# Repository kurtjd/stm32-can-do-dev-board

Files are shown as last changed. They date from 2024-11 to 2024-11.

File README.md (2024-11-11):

# STM32 CAN-Do! Development Board
|Layout|3D View|
|---|---|
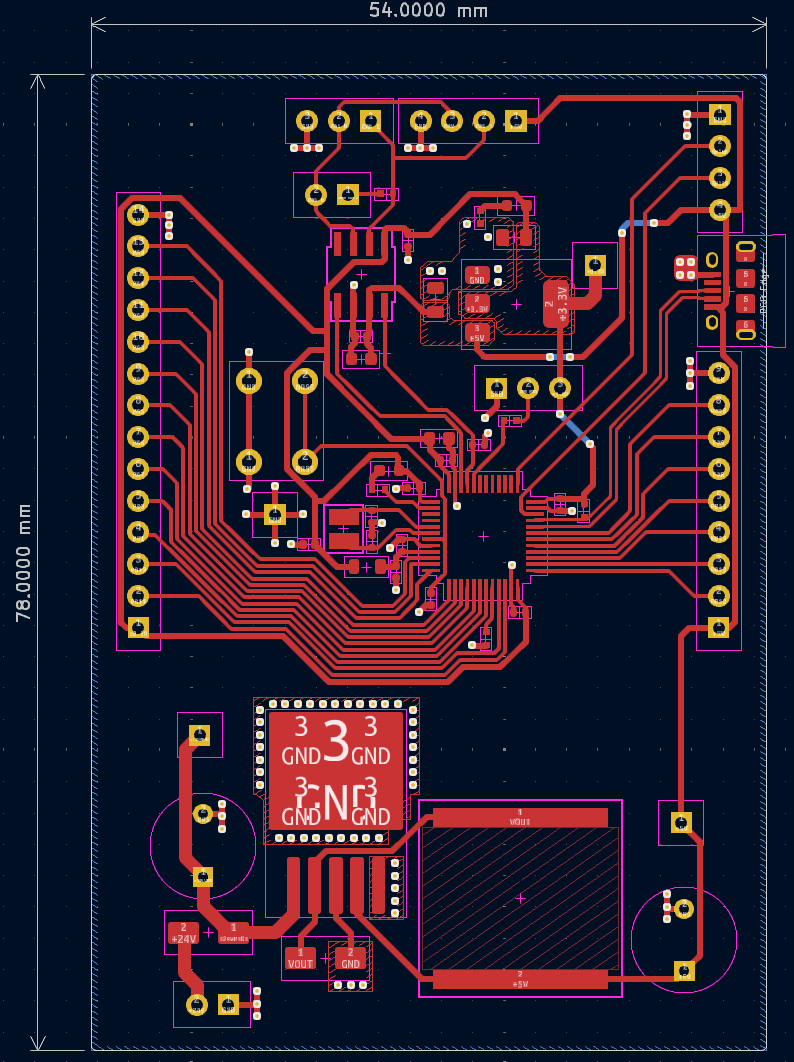
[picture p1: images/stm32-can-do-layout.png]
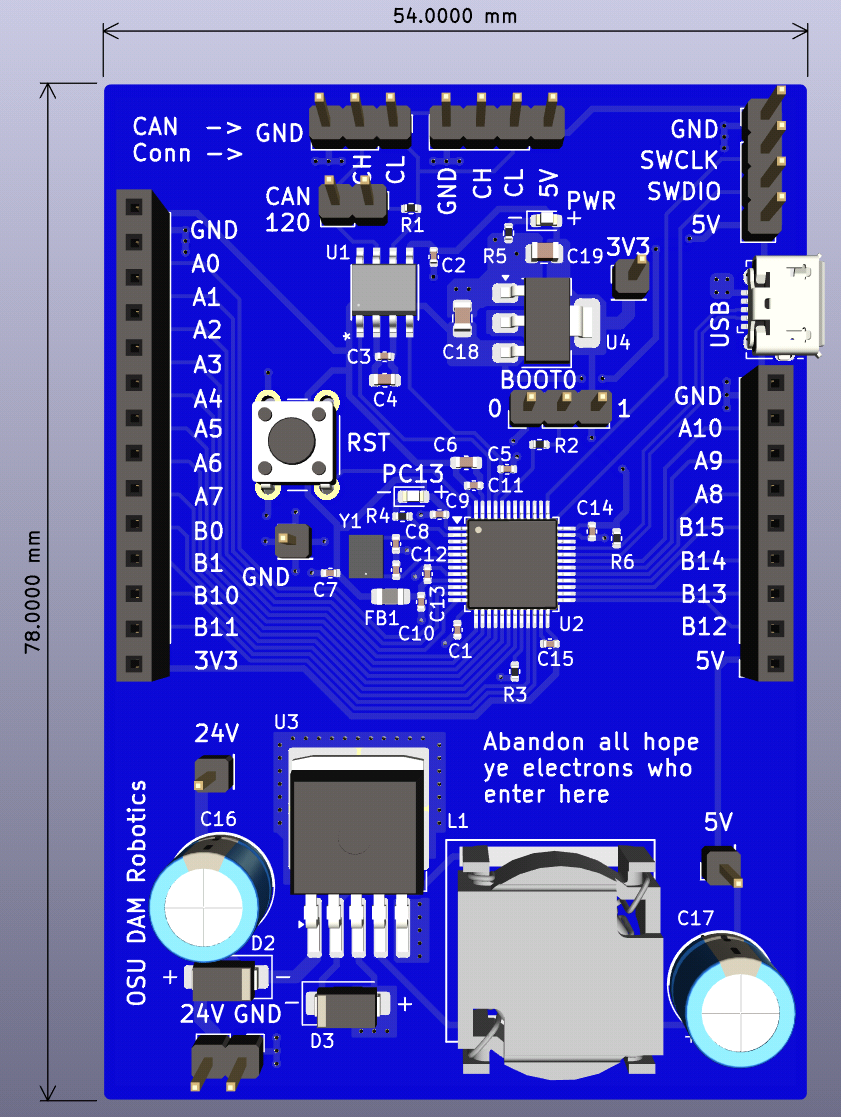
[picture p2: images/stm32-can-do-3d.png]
|||

A development board featuring:
- A STM32F103C8 microcontroller
- External high-speed crystal oscillator
- GPIO breakout, SWD and USB connectors
- CAN transceiver
- 5V LDO regulator
- 24V buck converter

This was primarily designed for testing CAN communication and voltage regulation before a
final design which will be used in the OSU DAM Robotics Club Mars Rover gripper.

This board is a bit of a step up in complexity from my previous boards, and due to
time constraints, wasn't able to do as much due dillgence and research as I'd have likes.

In future boards/revisions, I would like to revisit voltage regulators as newer chips
could be used and give more care to layout (which is not done as well as it could be here).
Also plan to learn more about designing 4-layer boards as the CAN and USB signal routing here
is not great at all and could use additional layers for signal integrity and ease of routing.

## Schematic
See `stm32-can-do-schematic.pdf` for full board schematic.

## Manufacturing
See the `KiCad/Manufacturing` folder. This contains the necessary
Gerber and BOM files for manufacturing by JLCPCB.

## License
This project is licensed under the MIT license and is completely free to use and modify.

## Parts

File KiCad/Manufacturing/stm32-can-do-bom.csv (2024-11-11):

Reference | Value | Footprint | Qty | LCSC
C1,C2,C3,C9,C11,C13,C14,C15 | 100nF | Capacitor_SMD:C_0402_1005Metric | 8 | C1525
C4,C6 | 10uF | Capacitor_SMD:C_0603_1608Metric | 2 | C19702
C5 | 15pF | Capacitor_SMD:C_0402_1005Metric | 1 | C1548
C7,C10 | 1uF | Capacitor_SMD:C_0402_1005Metric | 2 | C52923
C8,C12 | 10pF | Capacitor_SMD:C_0402_1005Metric | 2 | C32949
C18,C19 | 22uF | Capacitor_SMD:C_0805_2012Metric | 2 | C45783
D1 | LED_USR | LED_SMD:LED_0603_1608Metric | 1 | C2286
D2,D3 | SS54 | Diode_SMD:D_SMA | 2 | C22452
D4 | LED_PWR | LED_SMD:LED_0603_1608Metric | 1 | C2286
FB1 | 100R | Inductor_SMD:L_0805_2012Metric | 1 | C1015
J4 | USB_B_Micro | Connector_USB:USB_Micro-B_Amphenol_10118194-0001LF_Horizontal | 1 | C132563
L1 | PE-53829SNLT1:112uH | PE53829SNLT:IND_829SNLT_PUL | 1 | C2453068
R1 | 120 | Resistor_SMD:R_0402_1005Metric | 1 | C25079
R2,R3 | 10k | Resistor_SMD:R_0402_1005Metric | 2 | C25744
R4,R5,R6 | 1k5 | Resistor_SMD:R_0402_1005Metric | 3 | C25867
U1 | ATA6561-GAQW-N | ATA6561:SOIC8_4P9X3P9MC_MCH | 1 | C616016
U2 | STM32F103C8T6 | Package_QFP:LQFP-48_7x7mm_P0.5mm | 1 | C8734
U3 | LM2596S-5 | Package_TO_SOT_SMD:TO-263-5_TabPin3 | 1 | C347421
U4 | AMS1117-3.3 | Package_TO_SOT_SMD:SOT-223-3_TabPin2 | 1 | C6186
Y1 | 8MHz | NX3225GD:XTAL_NX3225GD-8MHZ-STD-CRA-3_NDK | 1 | C889706

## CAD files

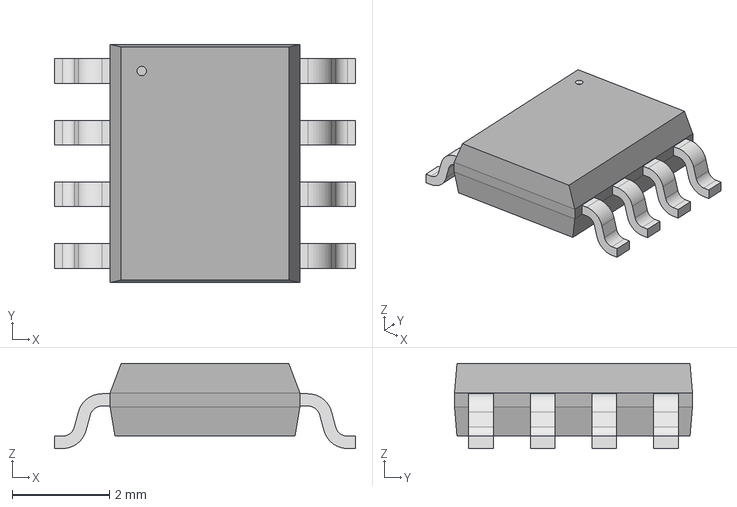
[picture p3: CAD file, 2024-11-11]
KiCad/ata6561/SOIC8_4P9X3P9MC_MCH.step
6.20 x 4.90 x 1.75 mm

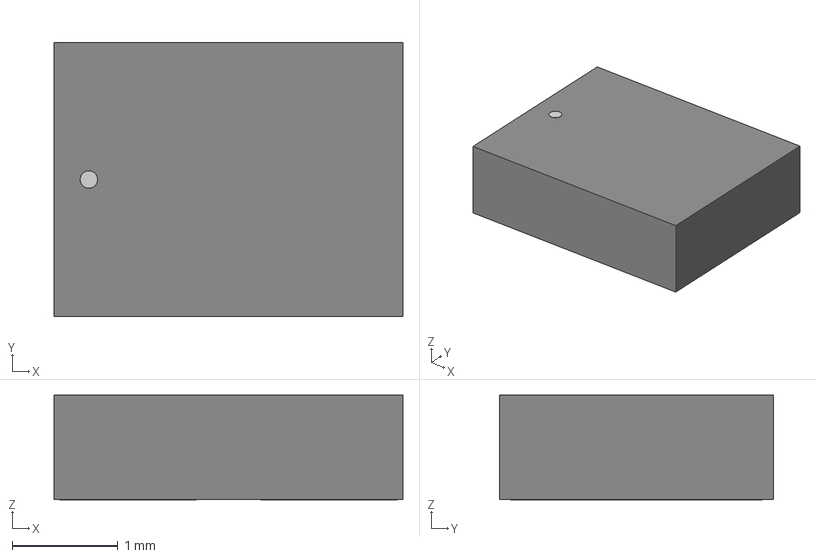
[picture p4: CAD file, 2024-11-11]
KiCad/nx3225gd/XTAL_NX3225GD-8MHZ-STD-CRA-3_NDK.step
3.30 x 2.59 x 0.993 mm

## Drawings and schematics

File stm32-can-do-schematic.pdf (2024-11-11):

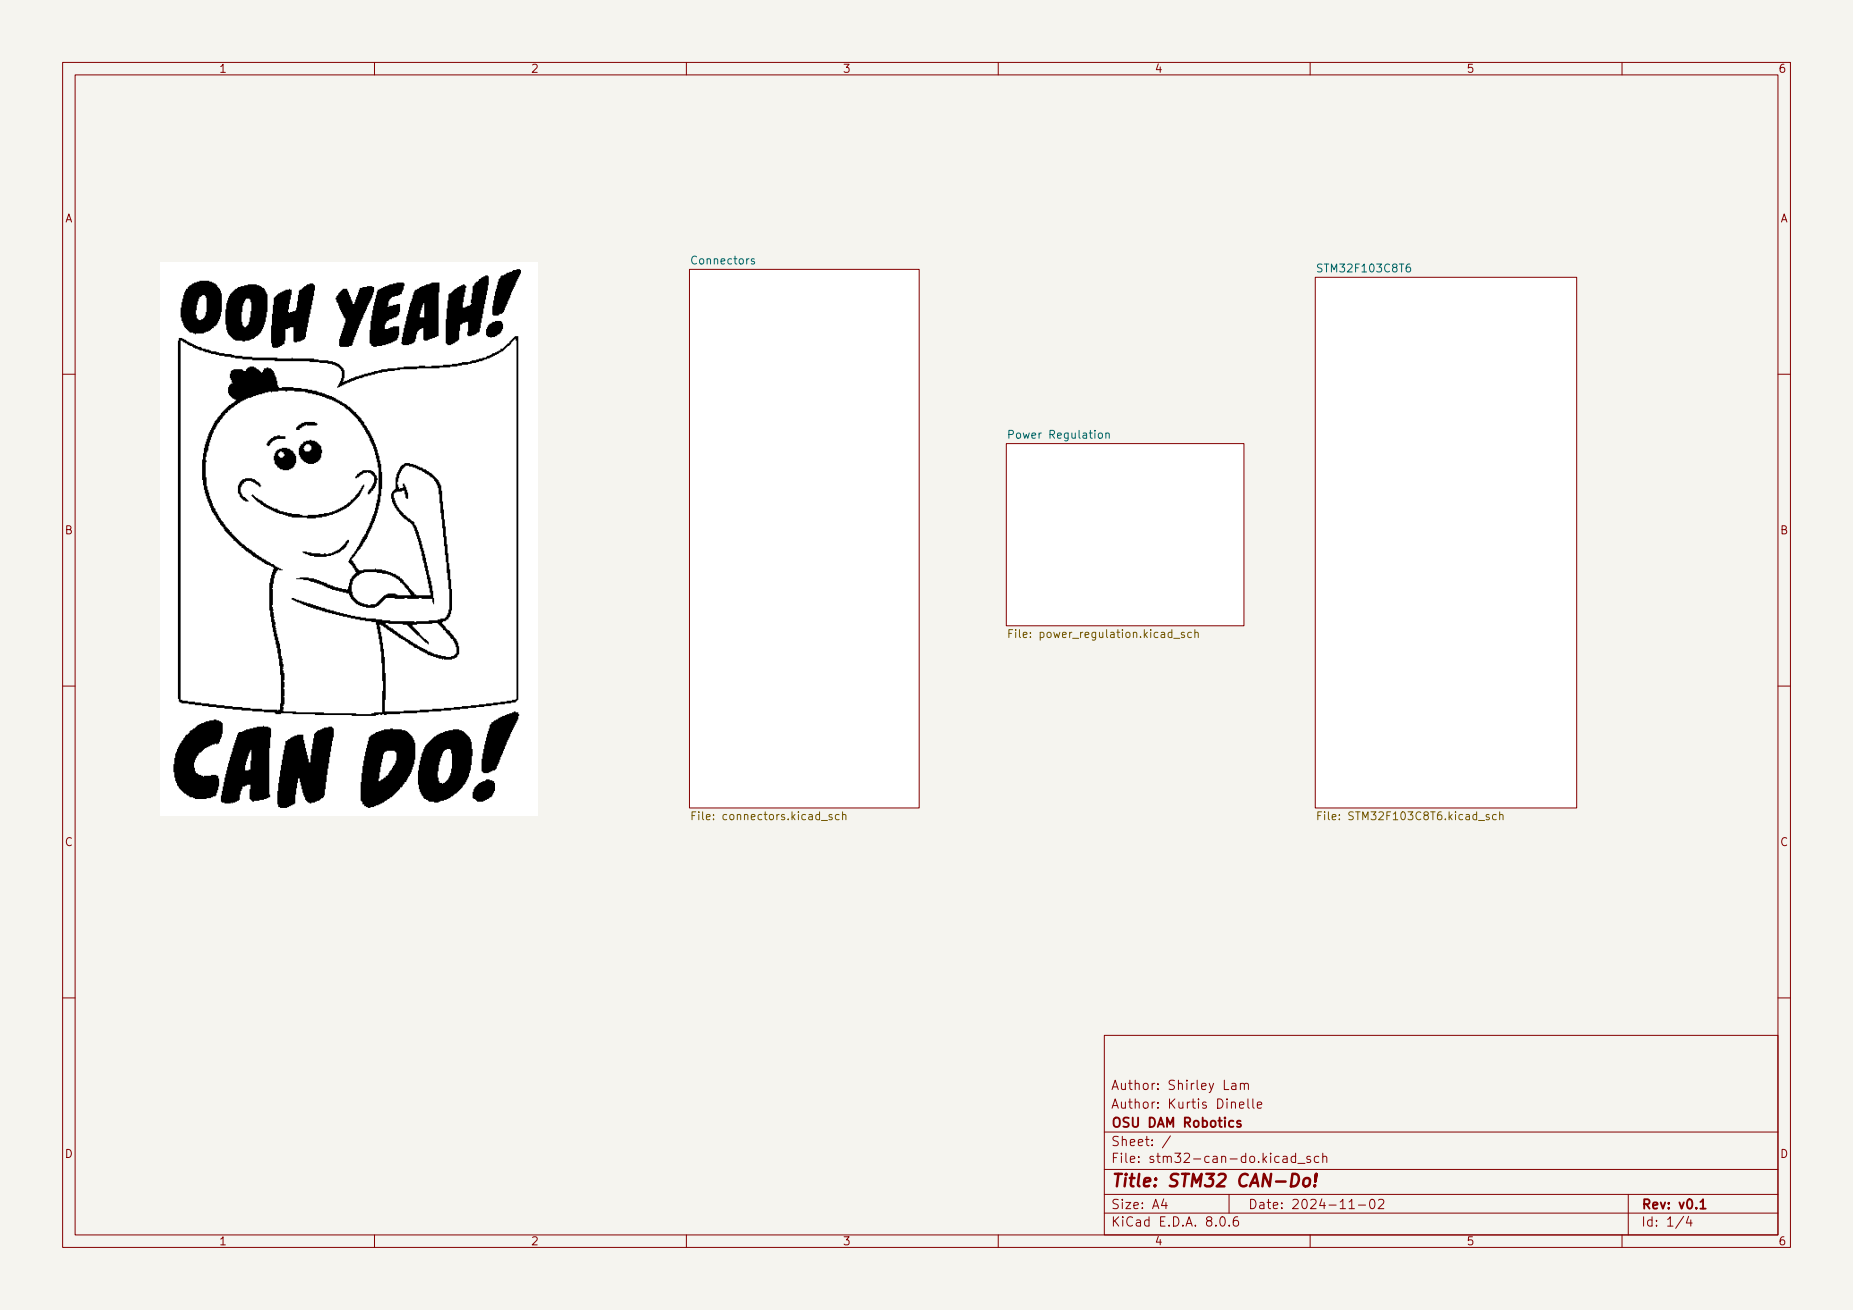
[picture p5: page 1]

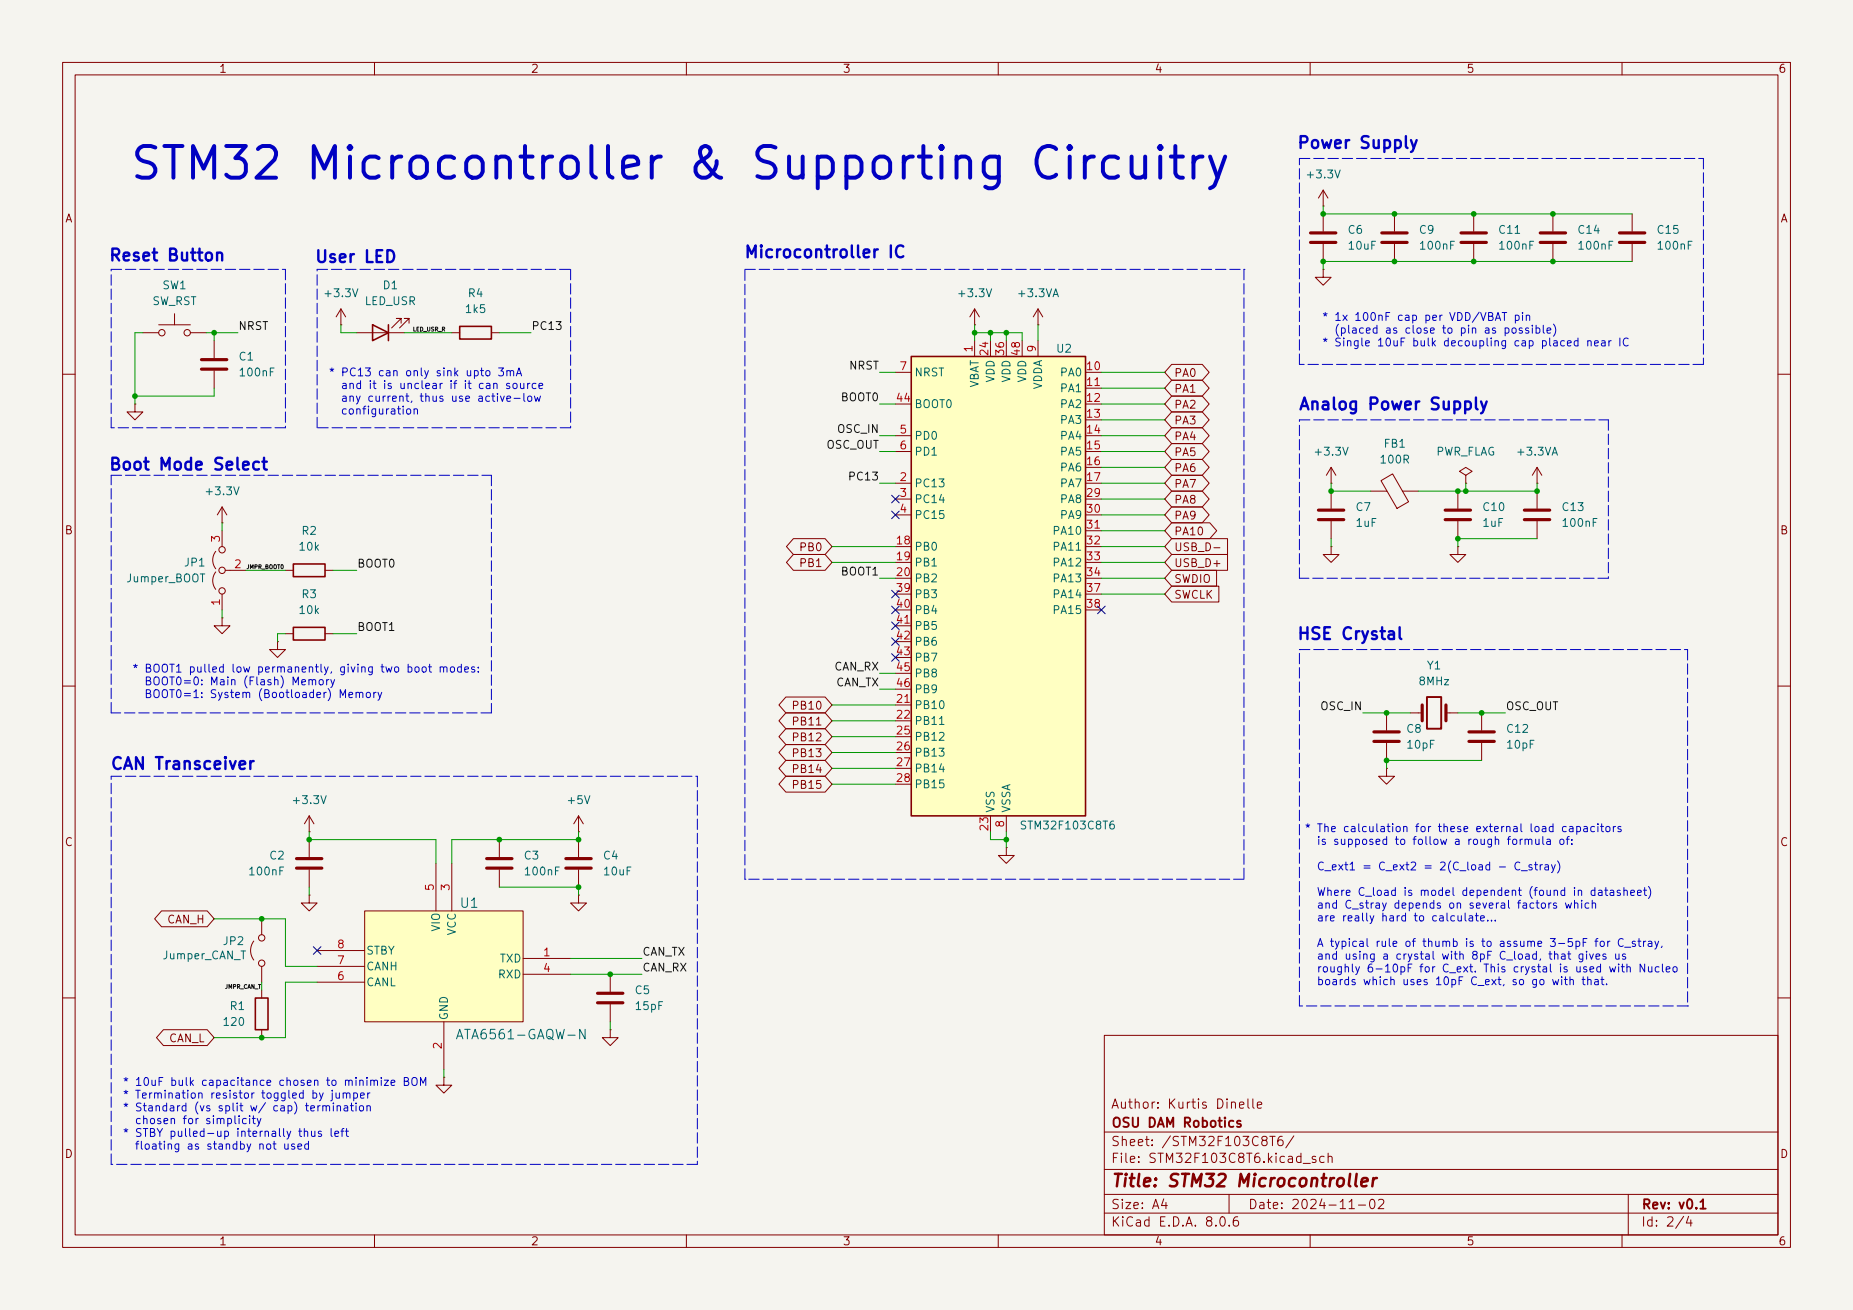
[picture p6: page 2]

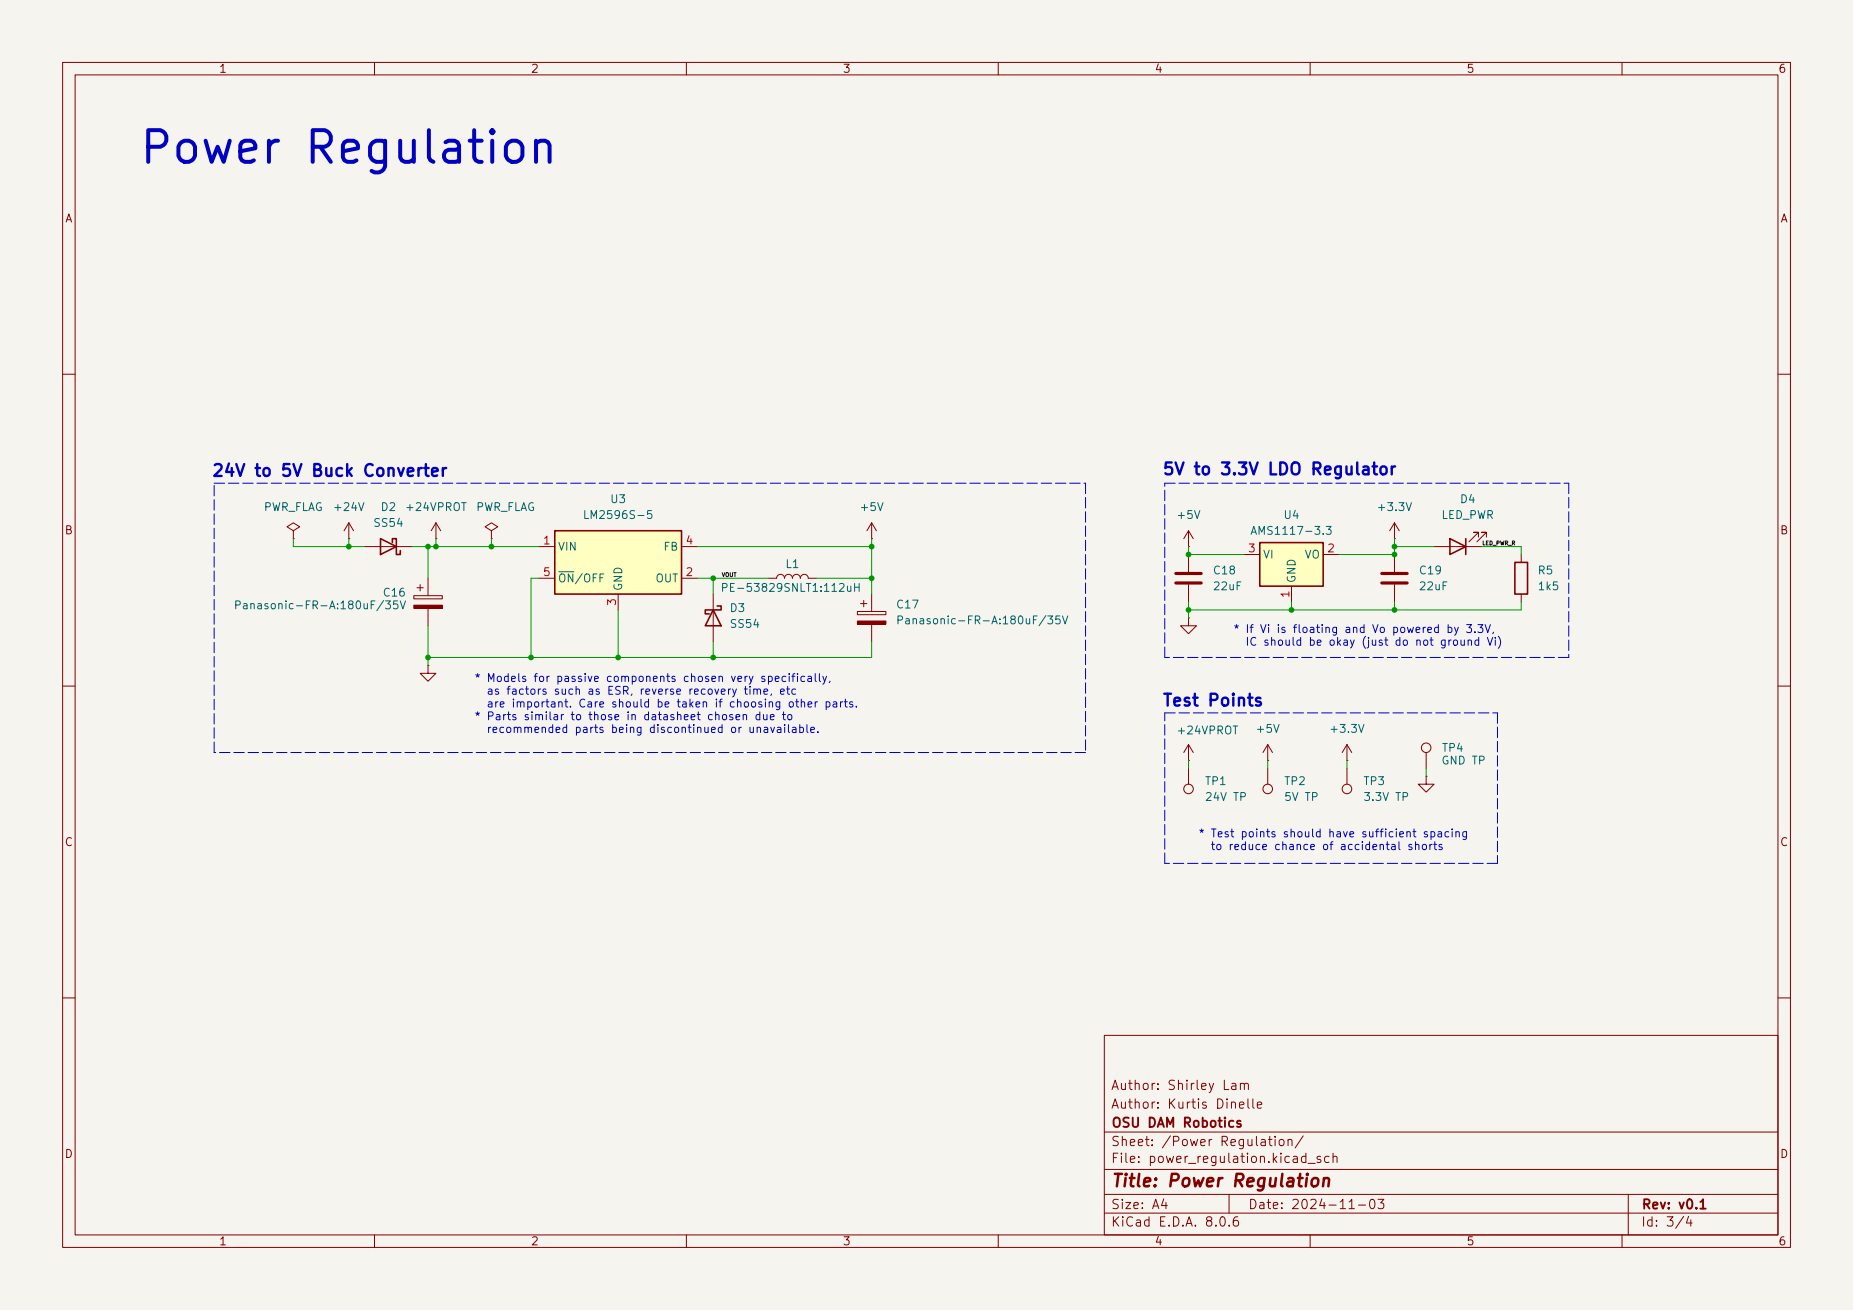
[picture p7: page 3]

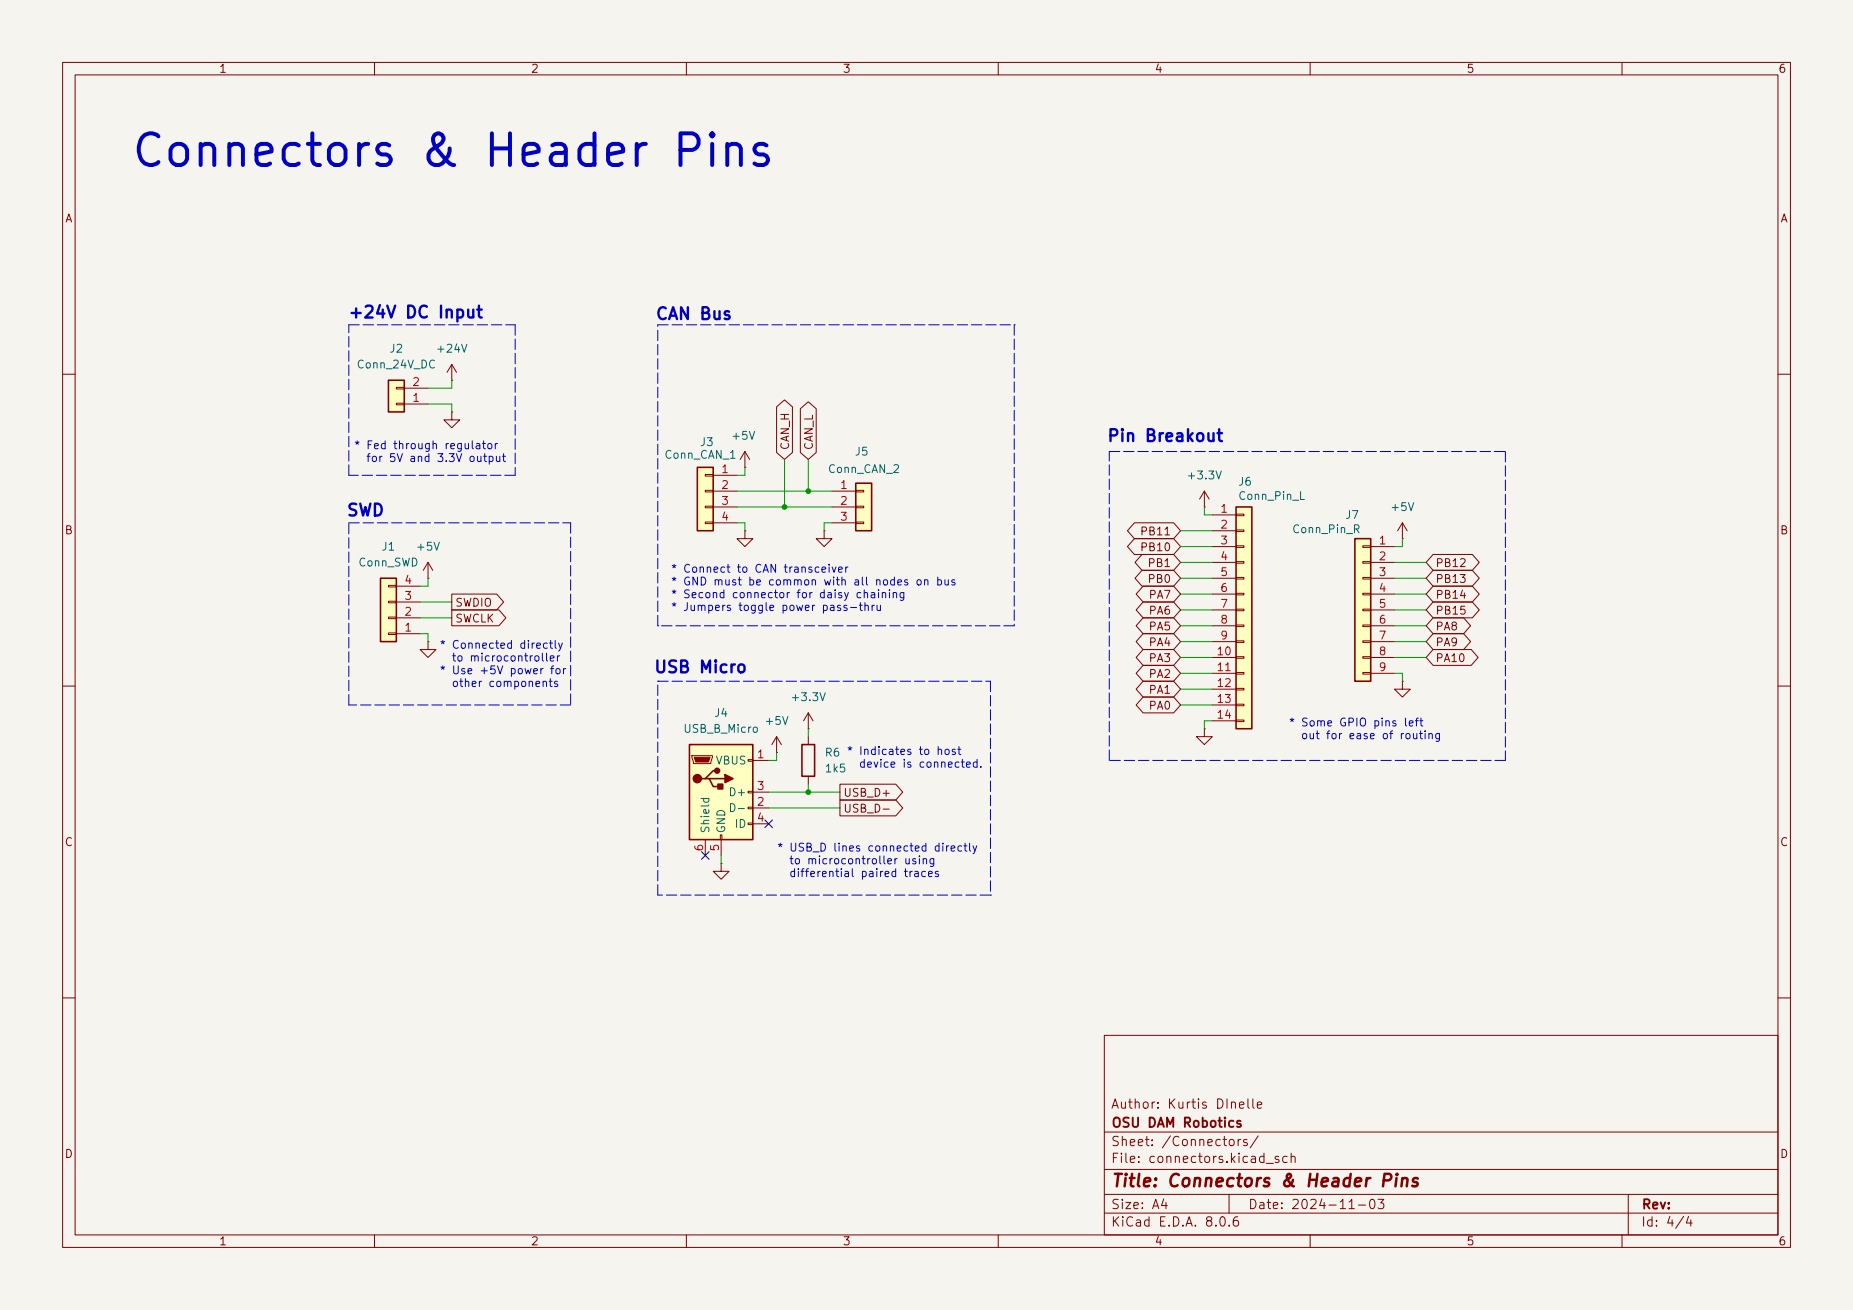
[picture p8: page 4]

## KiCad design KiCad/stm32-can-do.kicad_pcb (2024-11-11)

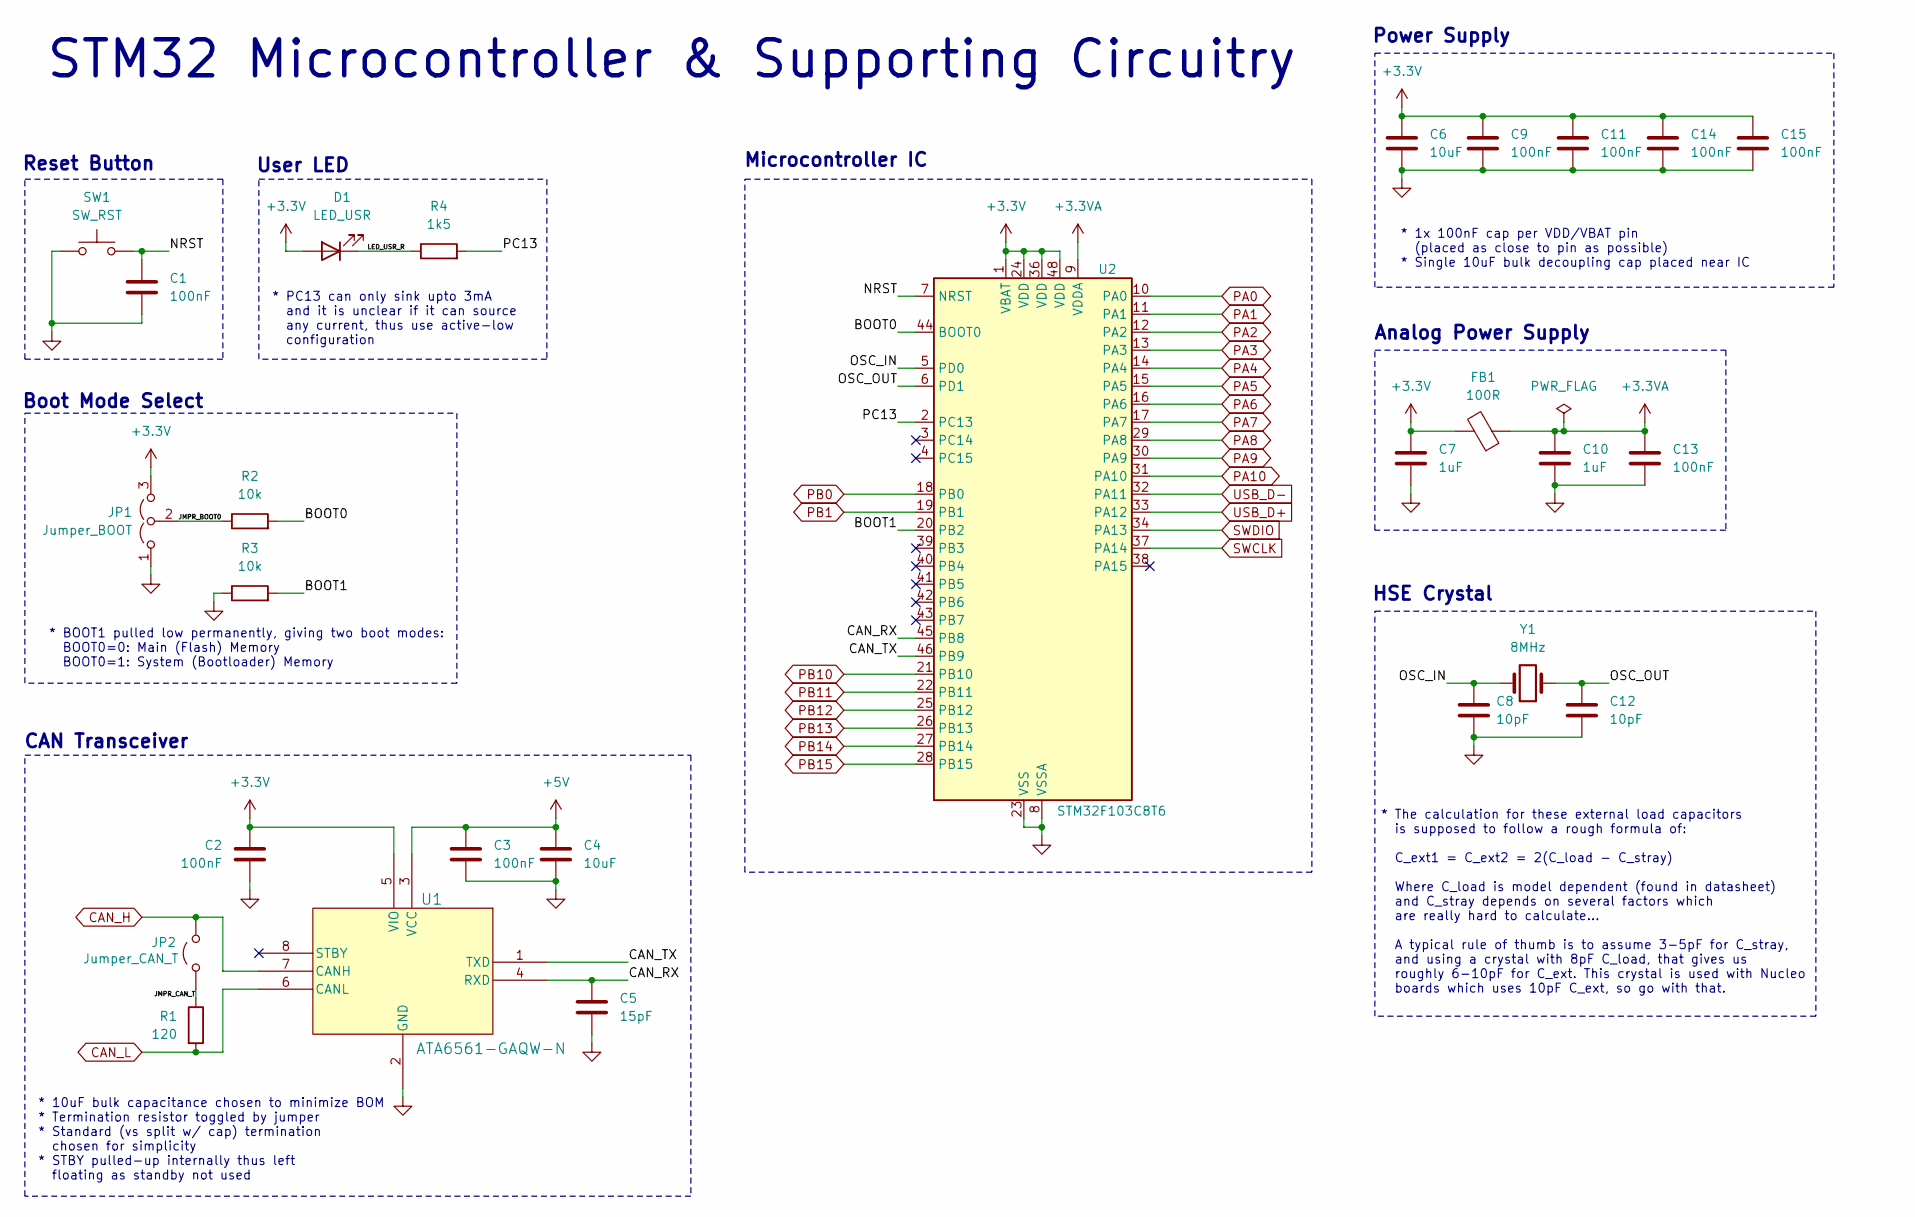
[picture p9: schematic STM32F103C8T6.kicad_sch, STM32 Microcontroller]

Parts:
C1, C2, C3, C9, C11, C13, C14, C15: 100nF; C_0402_1005Metric; LCSC C1525
C4, C6: 10uF; C_0603_1608Metric; LCSC C19702
C5: 15pF; C_0402_1005Metric; LCSC C1548
C7, C10: 1uF; C_0402_1005Metric; LCSC C52923
C8, C12: 10pF; C_0402_1005Metric; LCSC C32949
D1: LED_USR; LED_0603_1608Metric; LCSC C2286
FB1: 100R; L_0805_2012Metric; LCSC C1015
JP1: Jumper_BOOT; PinHeader_1x03_P2.54mm_Vertical
JP2: Jumper_CAN_T; PinHeader_1x02_P2.54mm_Vertical
R1: 120; R_0402_1005Metric; LCSC C25079
R2, R3: 10k; R_0402_1005Metric; LCSC C25744
R4: 1k5; R_0402_1005Metric; LCSC C25867
SW1: SW_RST; SW_PUSH_6mm
U1: ATA6561-GAQW-N; SOIC8_4P9X3P9MC_MCH; LCSC C616016
U2: STM32F103C8T6; LQFP-48_7x7mm_P0.5mm; LCSC C8734
Y1: 8MHz; XTAL_NX3225GD-8MHZ-STD-CRA-3_NDK; LCSC C889706

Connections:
+3.3V: C2.1, C6.1, C7.1, C9.1, C11.1, C14.1, C15.1, D1.2 (A), FB1.2, JP1.3 (B), U1.5 (VIO), U2.1 (VBAT), U2.24 (VDD), U2.36 (VDD), U2.48 (VDD); also elsewhere on the board
+3.3VA: C10.1, C13.1, FB1.1, U2.9 (VDDA)
+5V: C3.1, C4.1, U1.3 (VCC); also elsewhere on the board
/STM32F103C8T6/BOOT0: R2.2, U2.44 (BOOT0)
/STM32F103C8T6/BOOT1: R3.2, U2.20 (PB2)
/STM32F103C8T6/CAN_RX: C5.1, U1.4 (RXD), U2.45 (PB8)
/STM32F103C8T6/CAN_TX: U1.1 (TXD), U2.46 (PB9)
/STM32F103C8T6/JMPR_BOOT0: JP1.2 (C), R2.1
/STM32F103C8T6/JMPR_CAN_T: JP2.1 (A), R1.1
/STM32F103C8T6/LED_USR_R: D1.1 (K), R4.1
/STM32F103C8T6/NRST: C1.1, SW1.2, U2.7 (NRST)
/STM32F103C8T6/OSC_IN: C8.2, U2.5 (PD0), Y1.2
/STM32F103C8T6/OSC_OUT: C12.2, U2.6 (PD1), Y1.1
/STM32F103C8T6/PC13: R4.2, U2.2 (PC13)
CAN_H: JP2.2 (B), U1.7 (CANH); also elsewhere on the board
CAN_L: R1.2, U1.6 (CANL); also elsewhere on the board
GND: C1.2, C2.2, C3.2, C4.2, C5.2, C6.2, C7.2, C8.1, C9.2, C10.2, C11.2, C12.1, C13.2, C14.2, C15.2, JP1.1 (A), R3.1, SW1.1, U1.2 (GND), U2.8 (VSSA), U2.23 (VSS), U2.35 (VSS), U2.47 (VSS); also elsewhere on the board
PA0: U2.10 (PA0); also elsewhere on the board
PA1: U2.11 (PA1); also elsewhere on the board
PA2: U2.12 (PA2); also elsewhere on the board
PA3: U2.13 (PA3); also elsewhere on the board
PA4: U2.14 (PA4); also elsewhere on the board
PA5: U2.15 (PA5); also elsewhere on the board
PA6: U2.16 (PA6); also elsewhere on the board
PA7: U2.17 (PA7); also elsewhere on the board
PA8: U2.29 (PA8); also elsewhere on the board
PA9: U2.30 (PA9); also elsewhere on the board
PA10: U2.31 (PA10); also elsewhere on the board
PB0: U2.18 (PB0); also elsewhere on the board
PB1: U2.19 (PB1); also elsewhere on the board
PB10: U2.21 (PB10); also elsewhere on the board
PB11: U2.22 (PB11); also elsewhere on the board
PB12: U2.25 (PB12); also elsewhere on the board
PB13: U2.26 (PB13); also elsewhere on the board
PB14: U2.27 (PB14); also elsewhere on the board
PB15: U2.28 (PB15); also elsewhere on the board
SWCLK: U2.37 (PA14); also elsewhere on the board
SWDIO: U2.34 (PA13); also elsewhere on the board
USB_D+: U2.33 (PA12); also elsewhere on the board
USB_D-: U2.32 (PA11); also elsewhere on the board

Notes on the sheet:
* PC13 can only sink upto 3mA and it is unclear if it can source any current, thus use active-low configuration
Power Supply
Boot Mode Select
User LED
Microcontroller IC
Reset Button
* BOOT1 pulled low permanently, giving two boot modes: BOOT0=0: Main (Flash) Memory BOOT0=1: System (Bootloader) Memory
* The calculation for these external load capacitors is supposed to follow a rough formula of: C_ext1 = C_ext2 = 2(C_load - C_stray) Where C_load is model dependent (found in datasheet) and C_stray depends on several factors which are really hard to calculate... A typical rule of thumb is to assume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
CAN Transceiver
HSE Crystal
* 1x 100nF cap per VDD/VBAT pin (placed as close to pin as possible) * Single 10uF bulk decoupling cap placed near IC
STM32 Microcontroller & Supporting Circuitry
Analog Power Supply
* 10uF bulk capacitance chosen to minimize BOM * Termination resistor toggled by jumper * Standard (vs split w/ cap) termination chosen for simplicity * STBY pulled-up internally thus left floating as standby not used

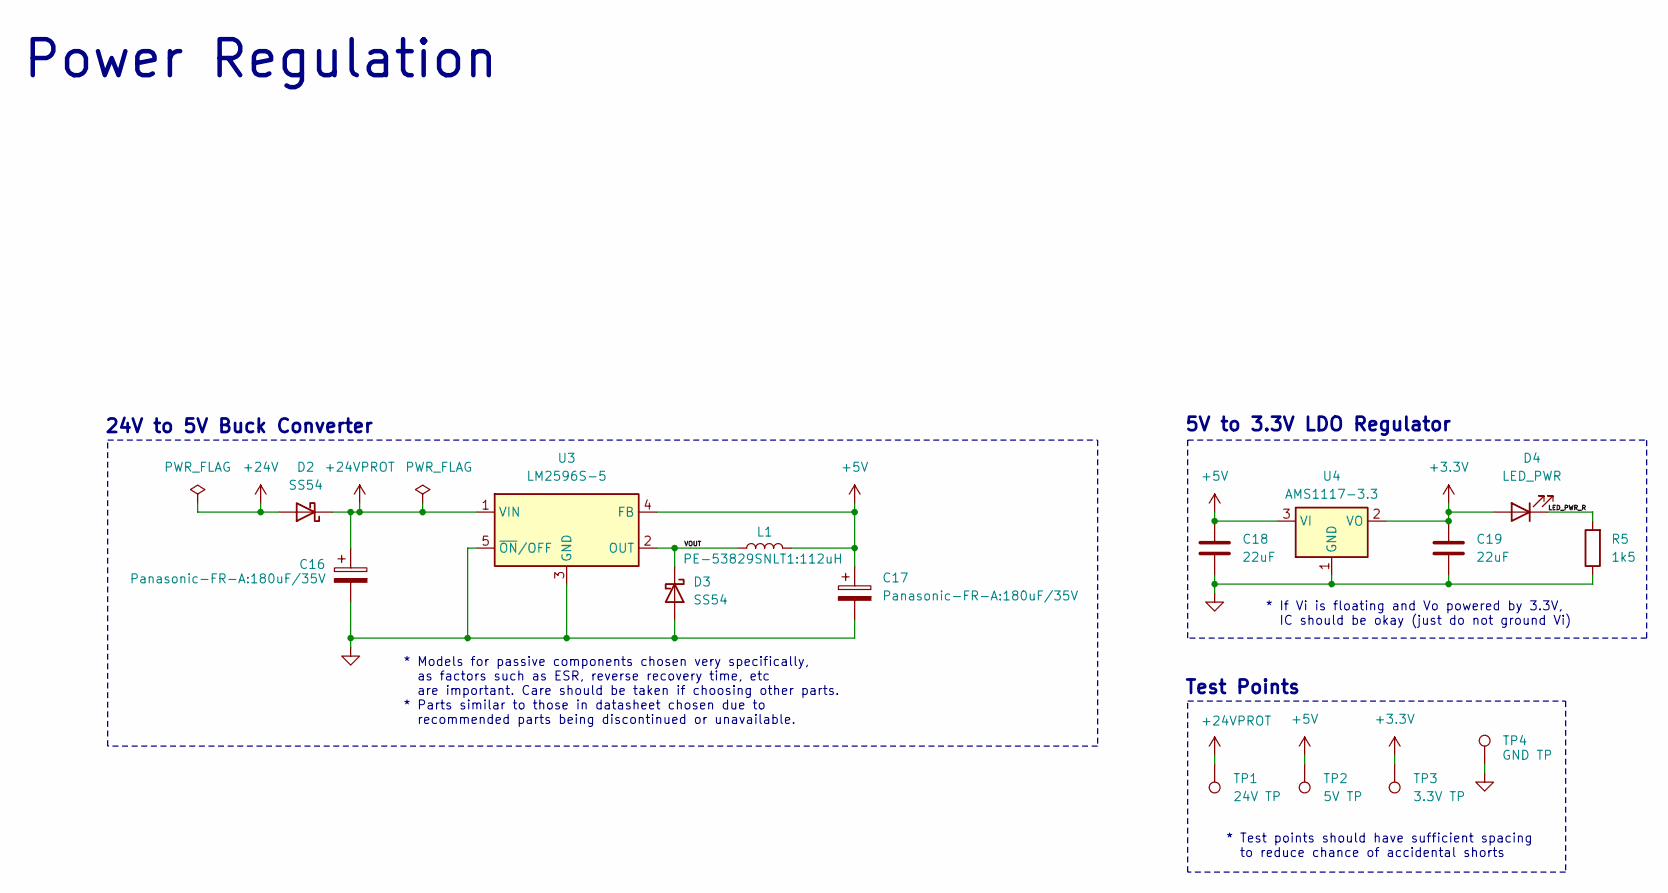
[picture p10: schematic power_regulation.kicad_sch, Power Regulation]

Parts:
C16, C17: Panasonic-FR-A:180uF/35V; CP_Radial_D8.0mm_P5.00mm
C18, C19: 22uF; C_0805_2012Metric; LCSC C45783
D2, D3: SS54; D_SMA; LCSC C22452
D4: LED_PWR; LED_0603_1608Metric; LCSC C2286
L1: PE-53829SNLT1:112uH; IND_829SNLT_PUL; LCSC C2453068
R5: 1k5; R_0402_1005Metric; LCSC C25867
TP1: 24V TP; PinHeader_1x01_P2.54mm_Vertical
TP2: 5V TP; PinHeader_1x01_P2.54mm_Vertical
TP3: 3.3V TP; PinHeader_1x01_P2.54mm_Vertical
TP4: GND TP; PinHeader_1x01_P2.54mm_Vertical
U3: LM2596S-5; TO-263-5_TabPin3; LCSC C347421
U4: AMS1117-3.3; SOT-223-3_TabPin2; LCSC C6186

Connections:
+3.3V: C19.1, D4.2 (A), TP3.1, U4.2 (VO); also elsewhere on the board
+5V: C17.1, C18.1, L1.2, TP2.1, U3.4 (FB), U4.3 (VI); also elsewhere on the board
+24V: D2.2 (A); also elsewhere on the board
+24VPROT: C16.1, D2.1 (K), TP1.1, U3.1 (VIN)
/Power Regulation/LED_PWR_R: D4.1 (K), R5.2
/Power Regulation/VOUT: D3.1 (K), L1.1, U3.2 (OUT)
GND: C16.2, C17.2, C18.2, C19.2, D3.2 (A), R5.1, TP4.1, U3.3 (GND), U3.5 (~ON/OFF), U4.1 (GND); also elsewhere on the board

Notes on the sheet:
24V to 5V Buck Converter
5V to 3.3V LDO Regulator
* If Vi is floating and Vo powered by 3.3V, IC should be okay (just do not ground Vi)
Test Points
* Models for passive components chosen very specifically, as factors such as ESR, reverse recovery time, etc are important. Care should be taken if choosing other parts. * Parts similar to those in datasheet chosen due to recommended parts being discontinued or unavailable.
* Test points should have sufficient spacing to reduce chance of accidental shorts
Power Regulation

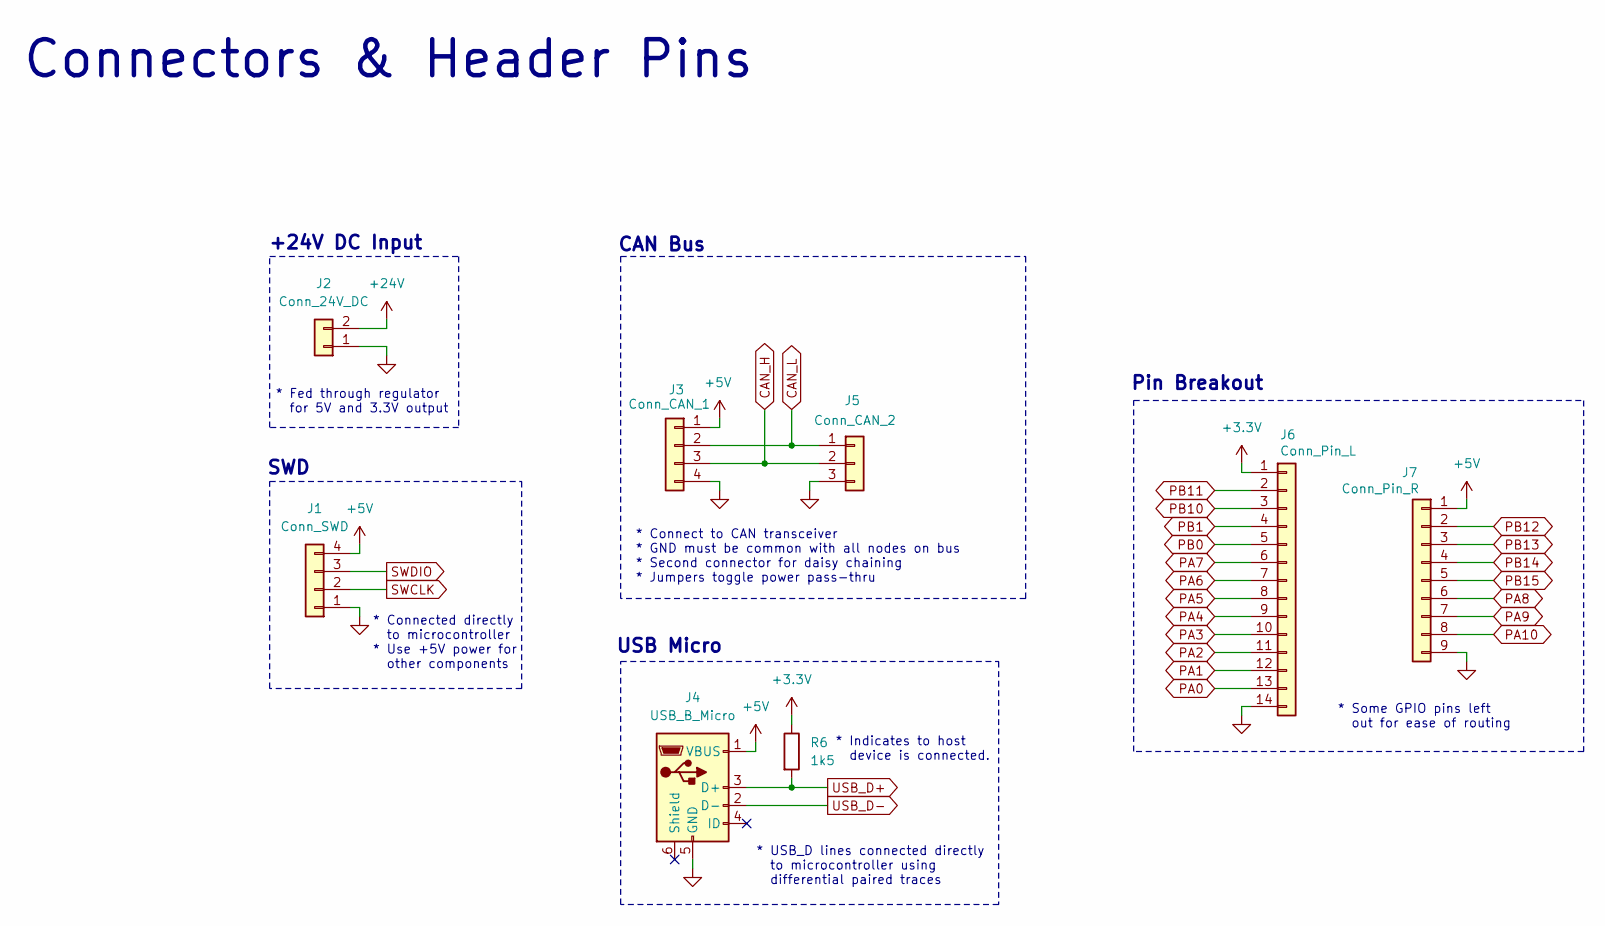
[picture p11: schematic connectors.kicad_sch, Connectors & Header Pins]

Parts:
J1: Conn_SWD; PinHeader_1x04_P2.54mm_Vertical
J2: Conn_24V_DC; PinHeader_1x02_P2.54mm_Vertical
J3: Conn_CAN_1; PinHeader_1x04_P2.54mm_Vertical
J4: USB_B_Micro; USB_Micro-B_Amphenol_10118194-0001LF_Horizontal; LCSC C132563
J5: Conn_CAN_2; PinHeader_1x03_P2.54mm_Vertical
J6: Conn_Pin_L; PinSocket_1x14_P2.54mm_Vertical
J7: Conn_Pin_R; PinSocket_1x09_P2.54mm_Vertical
R6: 1k5; R_0402_1005Metric; LCSC C25867

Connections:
+3.3V: J6.1, R6.1; also elsewhere on the board
+5V: J1.4, J3.1, J4.1 (VBUS), J7.1; also elsewhere on the board
+24V: J2.2; also elsewhere on the board
CAN_H: J3.3, J5.2; also elsewhere on the board
CAN_L: J3.2, J5.1; also elsewhere on the board
GND: J1.1, J2.1, J3.4, J4.5 (GND), J5.3, J6.14, J7.9; also elsewhere on the board
PA0: J6.13; also elsewhere on the board
PA1: J6.12; also elsewhere on the board
PA2: J6.11; also elsewhere on the board
PA3: J6.10; also elsewhere on the board
PA4: J6.9; also elsewhere on the board
PA5: J6.8; also elsewhere on the board
PA6: J6.7; also elsewhere on the board
PA7: J6.6; also elsewhere on the board
PA8: J7.6; also elsewhere on the board
PA9: J7.7; also elsewhere on the board
PA10: J7.8; also elsewhere on the board
PB0: J6.5; also elsewhere on the board
PB1: J6.4; also elsewhere on the board
PB10: J6.3; also elsewhere on the board
PB11: J6.2; also elsewhere on the board
PB12: J7.2; also elsewhere on the board
PB13: J7.3; also elsewhere on the board
PB14: J7.4; also elsewhere on the board
PB15: J7.5; also elsewhere on the board
SWCLK: J1.2; also elsewhere on the board
SWDIO: J1.3; also elsewhere on the board
USB_D+: J4.3 (D+), R6.2; also elsewhere on the board
USB_D-: J4.2 (D-); also elsewhere on the board

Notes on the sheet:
* Fed through regulator for 5V and 3.3V output
Pin Breakout
SWD
* Some GPIO pins left out for ease of routing
* Connect to CAN transceiver * GND must be common with all nodes on bus * Second connector for daisy chaining * Jumpers toggle power pass-thru
+24V DC Input
Connectors & Header Pins
* Indicates to host device is connected.
* Connected directly to microcontroller * Use +5V power for other components
* USB_D lines connected directly to microcontroller using differential paired traces
USB Micro
CAN Bus

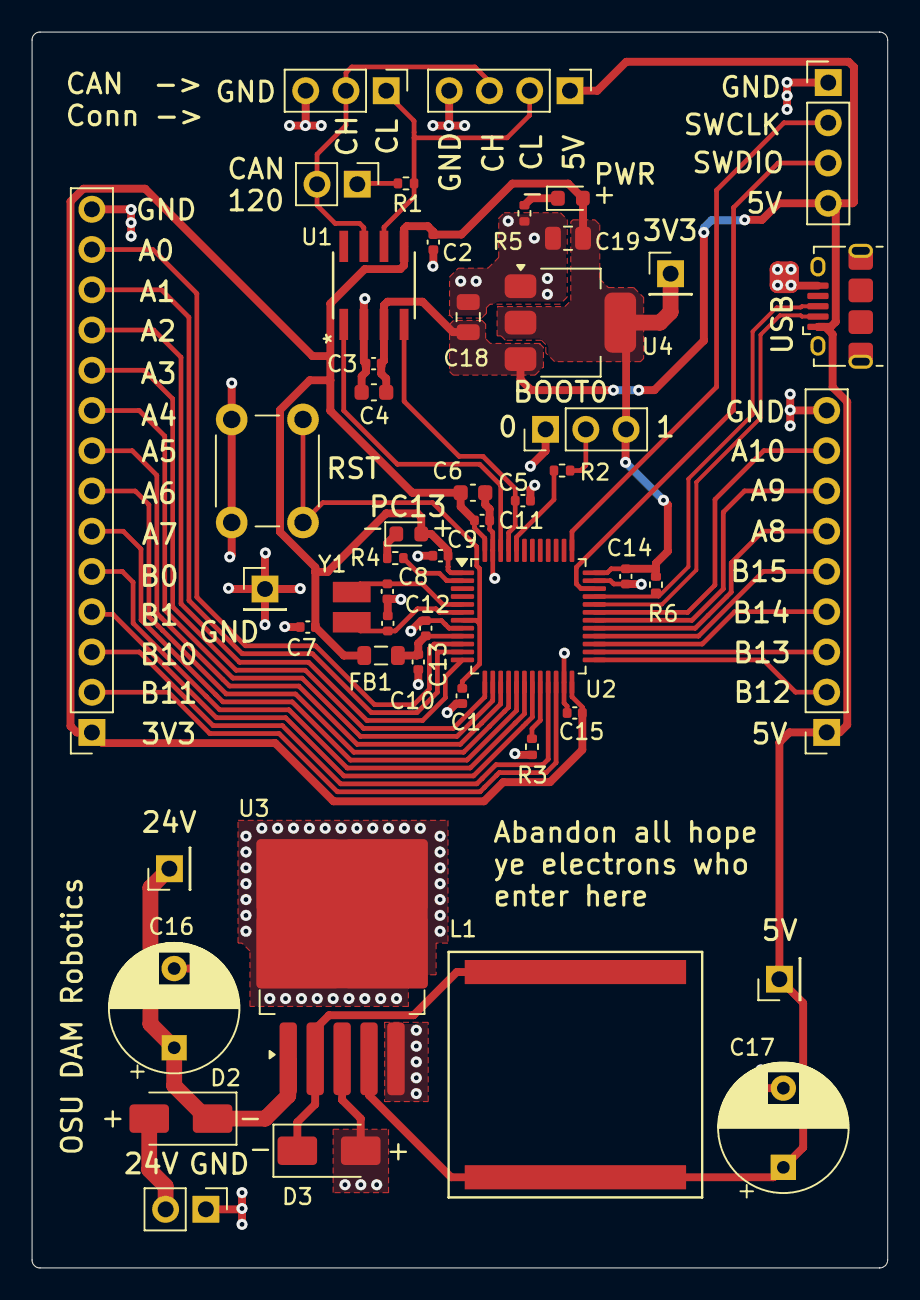
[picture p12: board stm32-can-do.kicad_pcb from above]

Board: 2 copper layers, 54.0 x 78.0 mm, 50 parts (0 on the bottom side), 44 nets.
